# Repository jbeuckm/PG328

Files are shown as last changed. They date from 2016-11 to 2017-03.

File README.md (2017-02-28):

# PG328

Program your JX8P/JX10/MKS70 with sliders or MIDI Sysex with this Atmega328 based PG800 variation.

A .96" OLED screen shows the status and parameter values and a rotary encoder with momentary push switch provides full PG800 interface capabilities.

### MID SYSEX

#### Prefix: 

* 0x41 // manufacturer ID
* 0x36 // IPR mode
* 0x01 // device ID
* 0x24 // (from MKS70)
* 0x20 // (from MKS70)

#### Suffix:

* 0x01 // Tone

* 0x0F: Reset potentiometer assignments.

### Status:

* 2/24/17: 8-slider pcb tested. This verifies that lots of sliders can work together and will serve as ADSR for EG1 and 2.

* 12/9/16: All Parameters select and display values according to their type. Some even have lil icons...

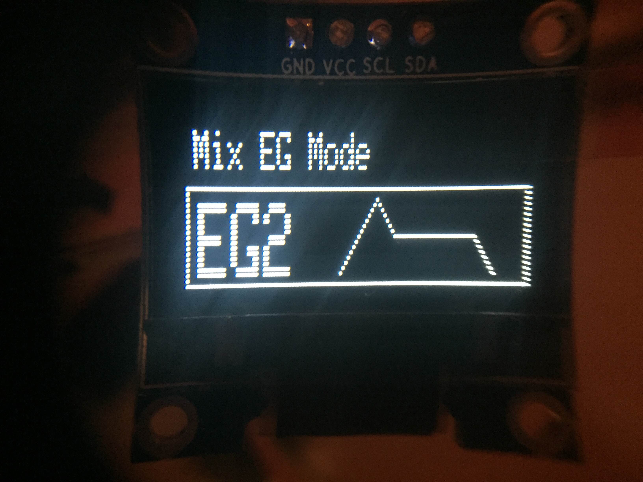
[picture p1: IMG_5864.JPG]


* 12/7/16: New Sysex message to clear all pot assignments

* 12/3/16: Stable control with encoder. Hold button to rotate parameter or just rotate to change value. Hold button down three seconds to assign slider of highest value to the current parameter.

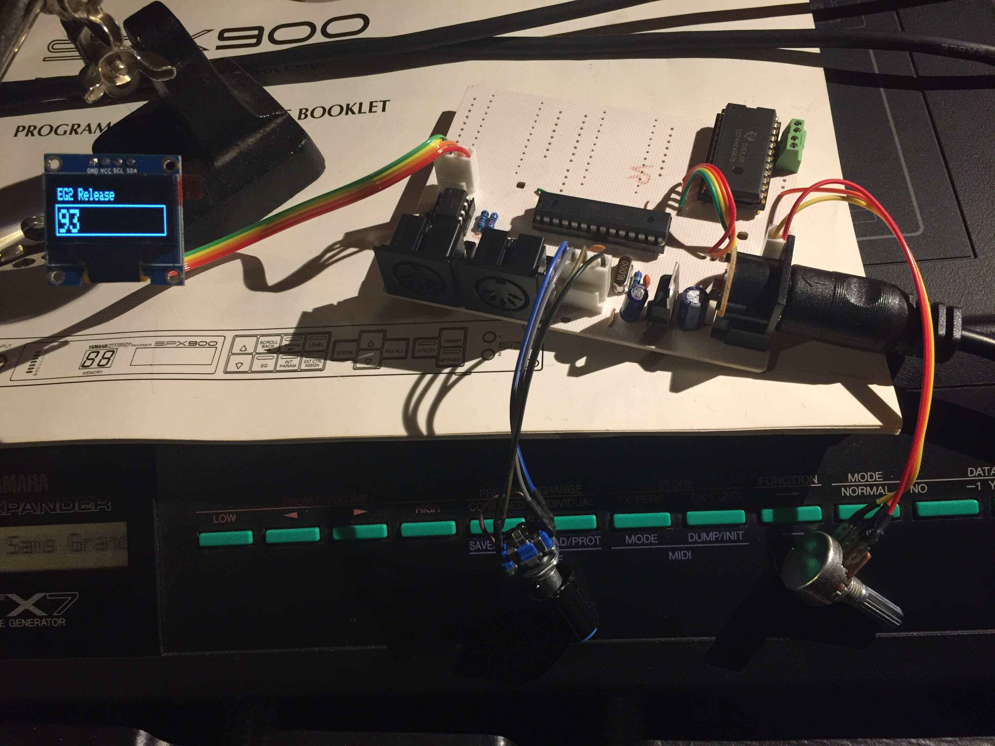
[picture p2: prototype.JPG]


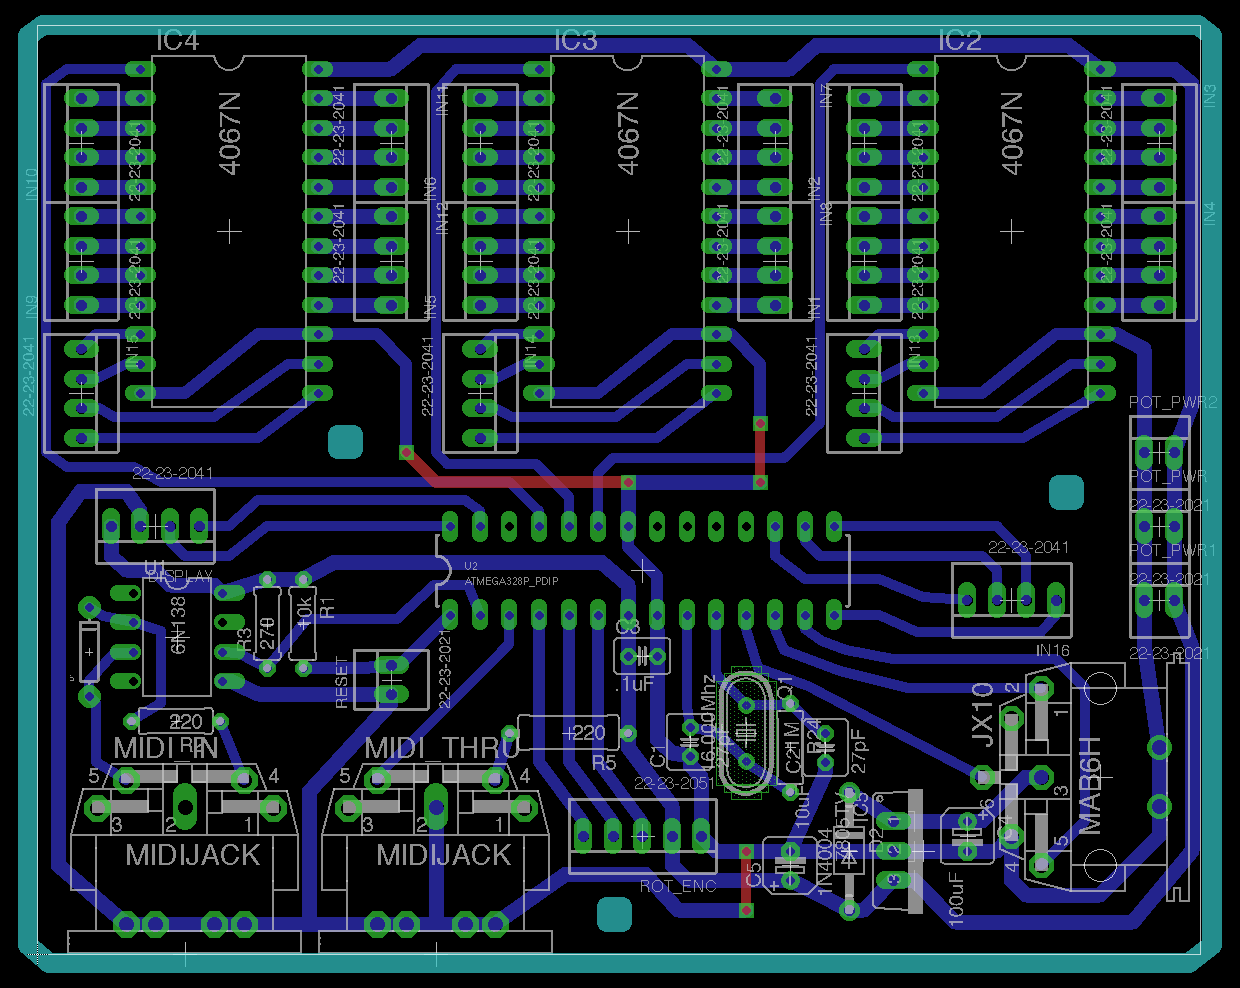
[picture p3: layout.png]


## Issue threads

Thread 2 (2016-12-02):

Set Aref a few mV below Vcc so pots always max analog in.

jbeuckm, 2016-12-02:
I am shifting the analog in value >> 3 to scale between 0 and 127. Sometimes the value will not move above 126. Setting Aref a few mV below Vcc should allow the pots to always reach max value since their max wiper voltage could exceed Aref by a tiny bit.

jbeuckm, 2016-12-06:
problem was software - no problem hitting 127 with the new rounding scheme.

Closed 2016-12-06.

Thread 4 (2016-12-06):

100nF Aref to Ground to Stabilize Analog Readings

jbeuckm, 2016-12-06:
https://forum.arduino.cc/index.php?topic=50189.msg358378#msg358378

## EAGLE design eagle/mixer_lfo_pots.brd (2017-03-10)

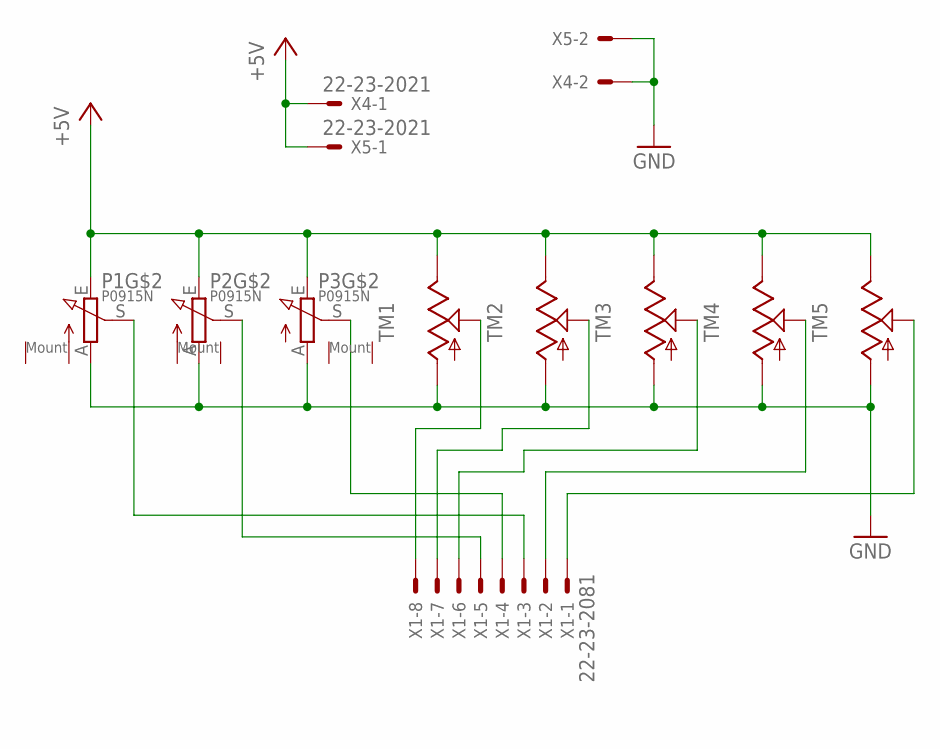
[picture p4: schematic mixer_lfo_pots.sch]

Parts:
P1, P2, P3: P0915N
TM1, TM2, TM3, TM4, TM5: TRIMSLIDE60; SLIDEPOT-60
X1: 22-23-2081
X4, X5: 22-23-2021

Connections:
+5V: P1.E, P2.E, P3.E, TM1.B, TM2.B, TM3.B, TM4.B, TM5.B, X4.1, X5.1
GND: P1.A, P2.A, P3.A, TM1.A, TM2.A, TM3.A, TM4.A, TM5.A, X4.2, X5.2
unnamed: P1.S, X1.3
unnamed: P2.S, X1.5
unnamed: P3.S, X1.4
unnamed: TM1.WIPER, X1.8
unnamed: TM2.WIPER, X1.7
unnamed: TM3.WIPER, X1.6
unnamed: TM4.WIPER, X1.2
unnamed: TM5.WIPER, X1.1

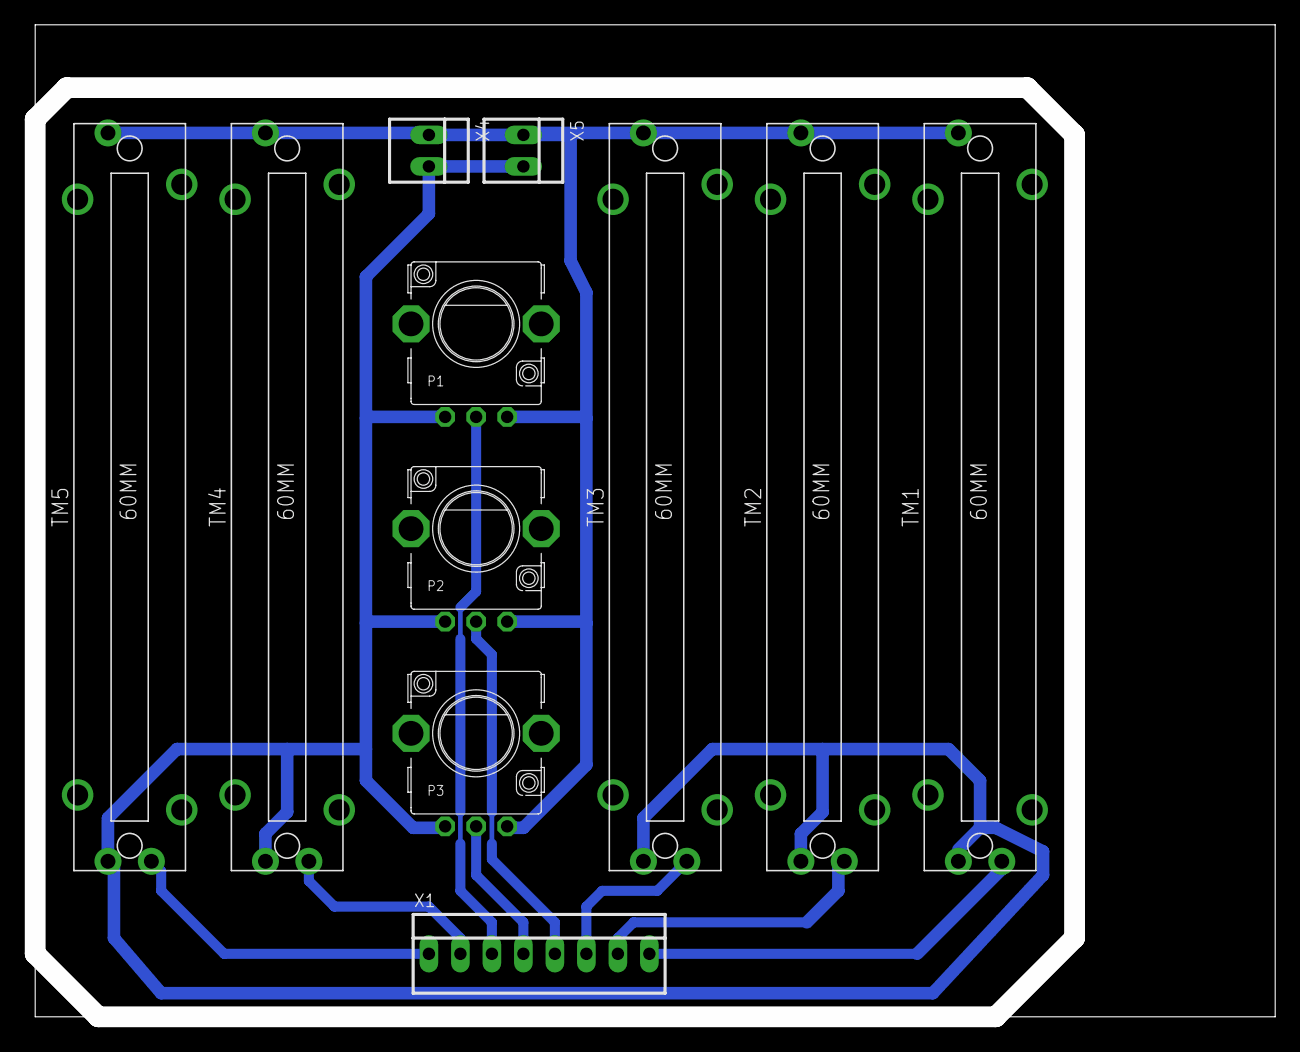
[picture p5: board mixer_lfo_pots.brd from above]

Board: 2 copper layers, 100.0 x 80.0 mm, 11 parts (0 on the bottom side), 10 nets.

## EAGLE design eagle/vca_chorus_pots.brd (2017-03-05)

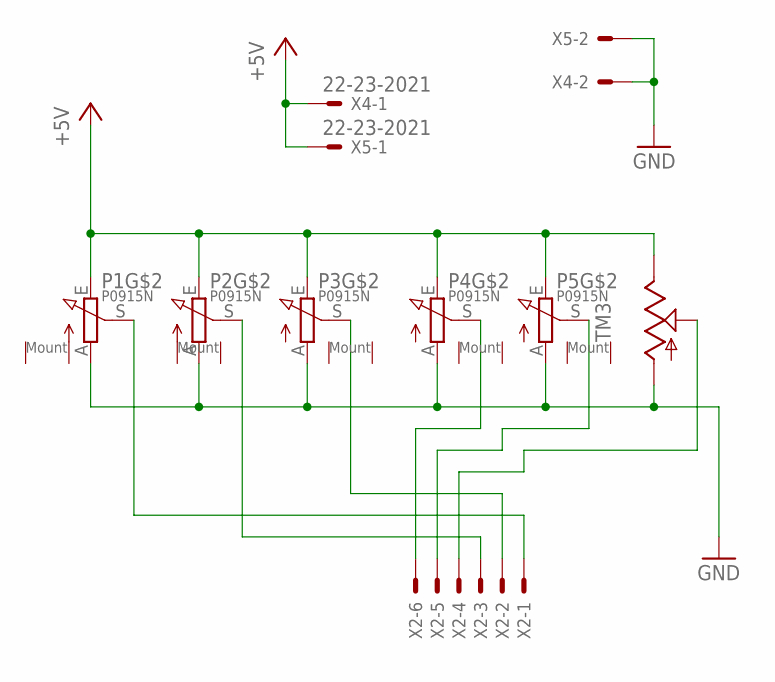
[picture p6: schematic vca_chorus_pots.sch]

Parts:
P1, P2, P3, P4, P5: P0915N
TM3: TRIMSLIDE60; SLIDEPOT-60
X2: 22-23-2061
X4, X5: 22-23-2021

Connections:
+5V: P1.E, P2.E, P3.E, P4.E, P5.E, TM3.B, X4.1, X5.1
GND: P1.A, P2.A, P3.A, P4.A, P5.A, TM3.A, X4.2, X5.2
unnamed: P1.S, X2.1
unnamed: P2.S, X2.3
unnamed: P3.S, X2.2
unnamed: P4.S, X2.6
unnamed: P5.S, X2.5
unnamed: TM3.WIPER, X2.4

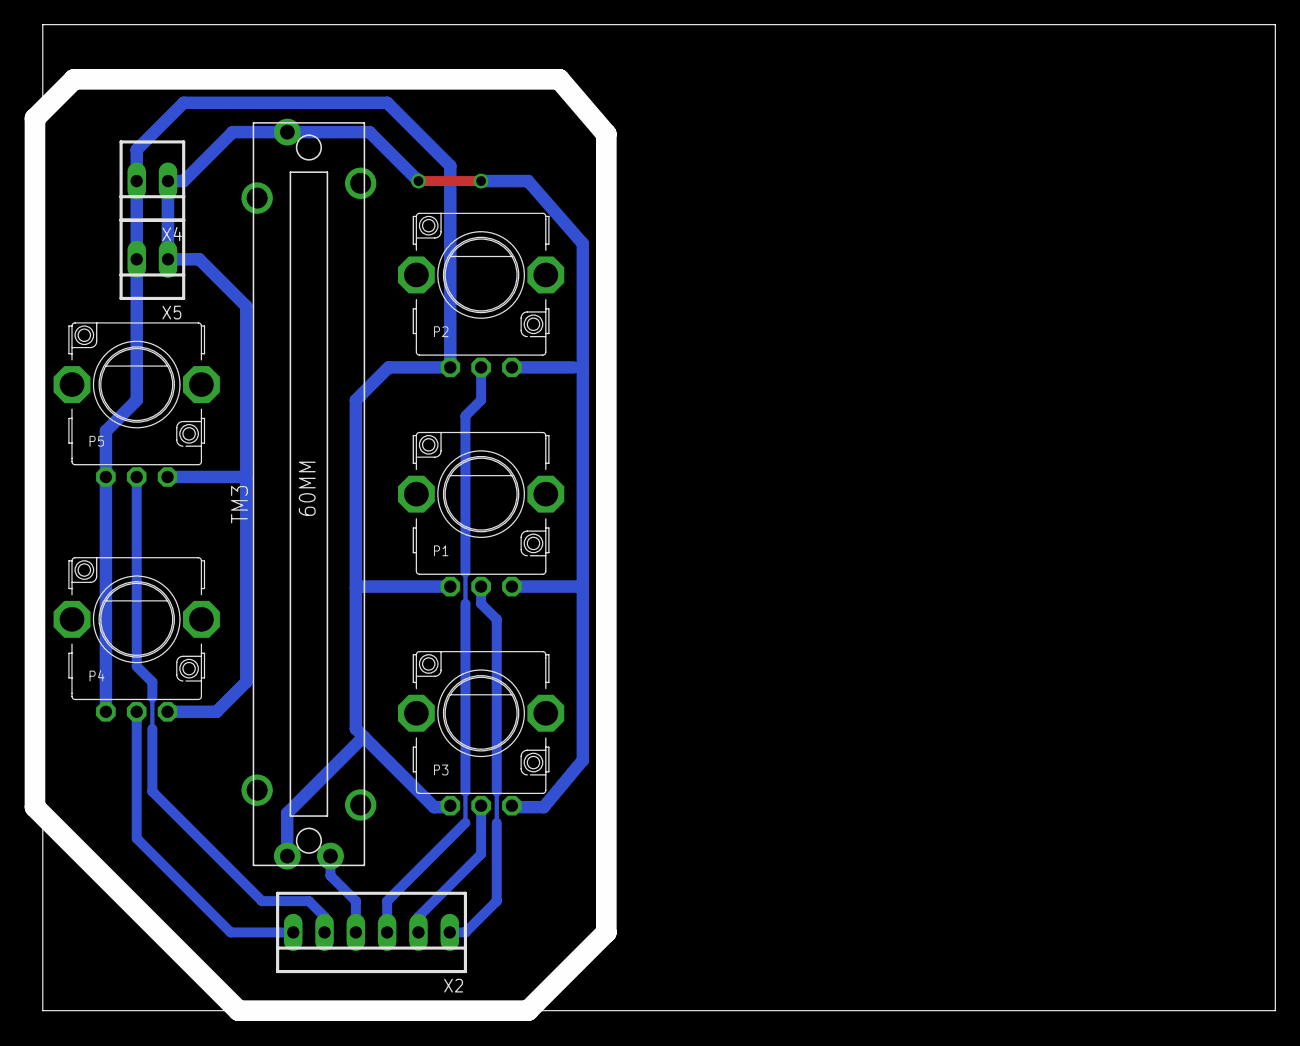
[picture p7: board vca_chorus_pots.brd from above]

Board: 2 copper layers, 100.6 x 80.0 mm, 9 parts (0 on the bottom side), 8 nets.

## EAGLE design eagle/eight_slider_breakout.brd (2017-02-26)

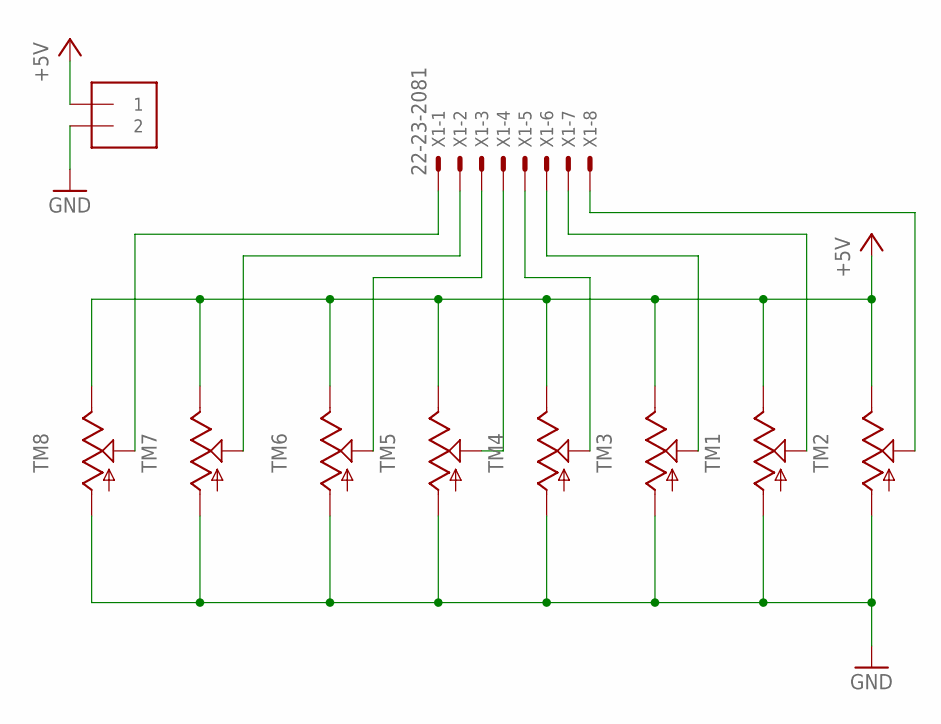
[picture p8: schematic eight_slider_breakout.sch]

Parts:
J1: 1X2-3.5MM
TM1, TM2, TM3, TM4, TM5, TM6, TM7, TM8: TRIMSLIDE60; SLIDEPOT-60
X1: 22-23-2081

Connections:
+5V: J1.1, TM1.B, TM2.B, TM3.B, TM4.B, TM5.B, TM6.B, TM7.B, TM8.B
GND: J1.2, TM1.A, TM2.A, TM3.A, TM4.A, TM5.A, TM6.A, TM7.A, TM8.A
unnamed: TM8.WIPER, X1.1
unnamed: TM7.WIPER, X1.2
unnamed: TM6.WIPER, X1.3
unnamed: TM5.WIPER, X1.4
unnamed: TM4.WIPER, X1.5
unnamed: TM3.WIPER, X1.6
unnamed: TM1.WIPER, X1.7
unnamed: TM2.WIPER, X1.8

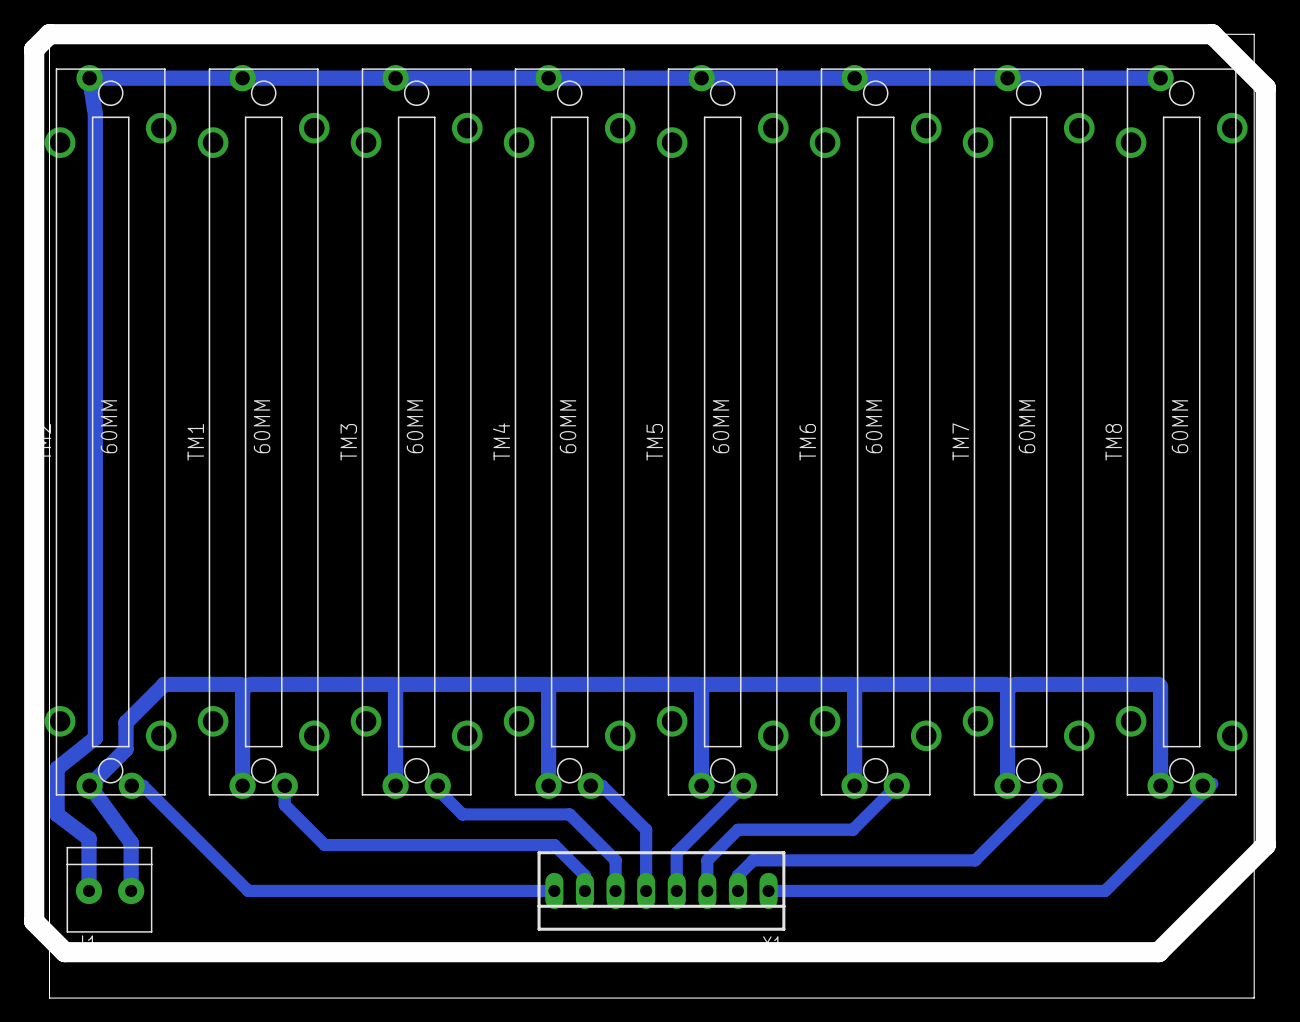
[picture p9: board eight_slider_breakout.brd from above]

Board: 2 copper layers, 102.2 x 80.0 mm, 10 parts (0 on the bottom side), 10 nets.

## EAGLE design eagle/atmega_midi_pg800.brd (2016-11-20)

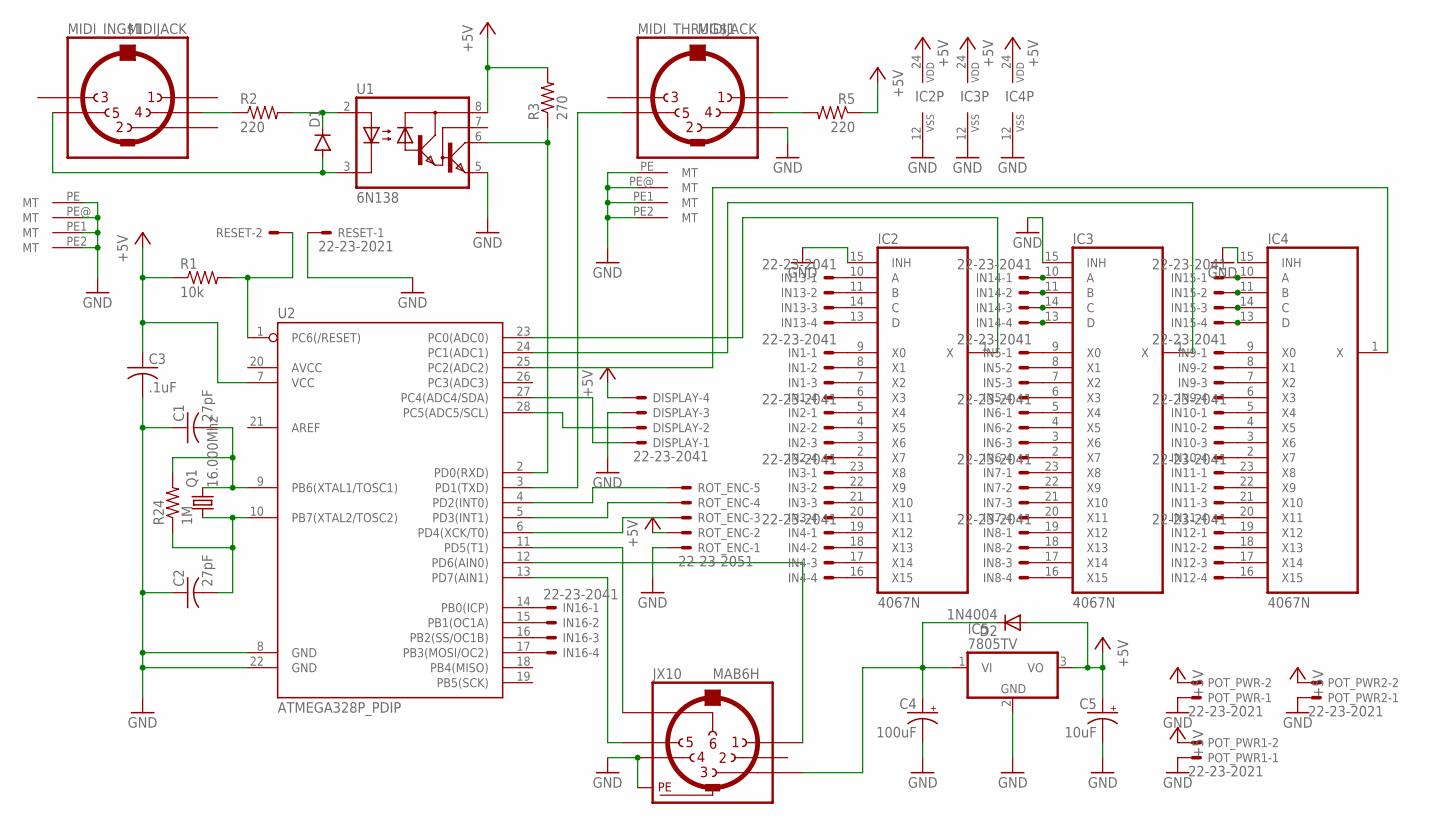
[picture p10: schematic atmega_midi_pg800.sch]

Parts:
C1, C2: 27pF; C025-040X050
C3: .1uF; C025-030X050
C4: 100uF; B45181A
C5: 10uF; B45181A
D1: DIODE1N4148; DIODE-1N4148
D2: 1N4004; DO41-10
DISPLAY: 22-23-2041
IC2, IC3, IC4: 4067N; DIL24-6
IC5: 7805TV; TO220V
IN1, IN2, IN3, IN4, IN5, IN6, IN7, IN8, IN9, IN10, IN11, IN12, IN13, IN14, IN15, IN16: 22-23-2041
JX10: MAB6H
MIDI_IN: MIDIJACK; CP-2350
MIDI_THRU: MIDIJACK; CP-2350
POT_PWR, POT_PWR1, POT_PWR2: 22-23-2021
Q1: 16.000Mhz; HC49/S
R1: 10k; 0207/7
R2: 220; 0207/7
R3: 270; 0207/7
R5: 220; 0309/10
R24: 1M; 0207/7
RESET: 22-23-2021
ROT_ENC: 22-23-2051
U1: 6N138; DIL08
U2: ATMEGA328P_PDIP; DIL28-3

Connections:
+5V: C3.1, C5.+, D2.A, DISPLAY.4, IC2.24 (VDD), IC3.24 (VDD), IC4.24 (VDD), IC5.3 (VO), POT_PWR.2, POT_PWR1.2, POT_PWR2.2, R1.1, R3.2, R5.1, ROT_ENC.2, U1.8 (VCC), U2.7 (VCC)
GND: C1.1, C2.1, C3.2, C4.-, C5.-, DISPLAY.3, IC2.12 (VSS), IC2.15 (INH), IC3.12 (VSS), IC3.15 (INH), IC4.12 (VSS), IC4.15 (INH), IC5.2 (GND), JX10.4, JX10.PE, JX10.PE@ (PE), MIDI_IN.PE (MT), MIDI_IN.PE1 (MT), MIDI_IN.PE2 (MT), MIDI_IN.PE@ (MT), MIDI_THRU.2, MIDI_THRU.PE (MT), MIDI_THRU.PE1 (MT), MIDI_THRU.PE2 (MT), MIDI_THRU.PE@ (MT), POT_PWR.1, POT_PWR1.1, POT_PWR2.1, RESET.1, ROT_ENC.1, U1.5 (GND), U2.8 (GND), U2.22 (GND)
unnamed: MIDI_THRU.4, R5.2
unnamed: IC4.1 (X), U2.25 (PC2(ADC2))
unnamed: D1.A, MIDI_IN.5, U1.3 (C)
unnamed: C1.2, Q1.2, R24.2, U2.9 (PB6(XTAL1/TOSC1))
unnamed: C2.2, Q1.1, R24.1, U2.10 (PB7(XTAL2/TOSC2))
unnamed: C4.+, D2.C, IC5.1 (VI), JX10.3
unnamed: D1.C, R2.2, U1.2 (A)
unnamed: MIDI_IN.4, R2.1
unnamed: JX10.6, U2.11 (PD5(T1))
unnamed: JX10.1, U2.12 (PD6(AIN0))
unnamed: JX10.5, U2.13 (PD7(AIN1))
unnamed: DISPLAY.2, U2.28 (PC5(ADC5/SCL))
unnamed: DISPLAY.1, U2.27 (PC4(ADC4/SDA))
unnamed: IC3.1 (X), U2.24 (PC1(ADC1))
unnamed: IC2.1 (X), U2.23 (PC0(ADC0))
unnamed: IN16.1, U2.14 (PB0(ICP))
unnamed: IN16.2, U2.15 (PB1(OC1A))
unnamed: IC3.10 (A), IN14.1
unnamed: IC3.11 (B), IN14.2
unnamed: IC2.9 (X0), IN1.1
unnamed: IC2.8 (X1), IN1.2
unnamed: IC2.7 (X2), IN1.3
unnamed: IC2.6 (X3), IN1.4
unnamed: IC2.5 (X4), IN2.1
unnamed: IC2.4 (X5), IN2.2
unnamed: IC2.3 (X6), IN2.3
unnamed: IC2.2 (X7), IN2.4
unnamed: IC2.23 (X8), IN3.1
unnamed: IC2.22 (X9), IN3.2
unnamed: R3.1, U1.6 (VO), U2.2 (PD0(RXD))
unnamed: IC2.21 (X10), IN3.3
unnamed: IC2.20 (X11), IN3.4
unnamed: IC2.19 (X12), IN4.1
unnamed: IC2.18 (X13), IN4.2
unnamed: IC2.17 (X14), IN4.3
unnamed: IC2.16 (X15), IN4.4
unnamed: IC3.9 (X0), IN5.1
unnamed: IC3.8 (X1), IN5.2
unnamed: IC3.7 (X2), IN5.3
unnamed: IC3.6 (X3), IN5.4
unnamed: IC3.5 (X4), IN6.1
unnamed: MIDI_THRU.5, U2.3 (PD1(TXD))
unnamed: R1.2, RESET.2, U2.1 (PC6(/RESET))
unnamed: IC3.4 (X5), IN6.2
unnamed: IC3.3 (X6), IN6.3
unnamed: IC3.2 (X7), IN6.4
unnamed: IC3.23 (X8), IN7.1
unnamed: IC3.22 (X9), IN7.2
unnamed: IC3.21 (X10), IN7.3
unnamed: IC3.20 (X11), IN7.4
unnamed: IC3.19 (X12), IN8.1
unnamed: IC3.18 (X13), IN8.2
unnamed: IC3.17 (X14), IN8.3
unnamed: IC3.16 (X15), IN8.4
unnamed: IC4.9 (X0), IN9.1
unnamed: IC4.8 (X1), IN9.2
unnamed: IC4.7 (X2), IN9.3
unnamed: IC4.6 (X3), IN9.4
unnamed: IC4.5 (X4), IN10.1
unnamed: IC4.4 (X5), IN10.2
unnamed: IC4.3 (X6), IN10.3
unnamed: IC4.2 (X7), IN10.4
unnamed: IC4.23 (X8), IN11.1
unnamed: IC4.22 (X9), IN11.2
unnamed: IC4.21 (X10), IN11.3
unnamed: IC4.20 (X11), IN11.4
unnamed: IC4.19 (X12), IN12.1
unnamed: IC4.18 (X13), IN12.2
unnamed: IC4.17 (X14), IN12.3
unnamed: IC4.16 (X15), IN12.4
unnamed: IC3.14 (C), IN14.3
unnamed: IC3.13 (D), IN14.4
unnamed: IC4.10 (A), IN15.1
unnamed: IC4.11 (B), IN15.2
unnamed: IC4.14 (C), IN15.3
unnamed: IC4.13 (D), IN15.4
unnamed: IN16.3, U2.16 (PB2(SS/OC1B))
unnamed: IN16.4, U2.17 (PB3(MOSI/OC2))
unnamed: IC2.13 (D), IN13.4
unnamed: IC2.14 (C), IN13.3
unnamed: IC2.11 (B), IN13.2
unnamed: IC2.10 (A), IN13.1
unnamed: ROT_ENC.5, U2.4 (PD2(INT0))
unnamed: ROT_ENC.4, U2.5 (PD3(INT1))
unnamed: ROT_ENC.3, U2.6 (PD4(XCK/T0))

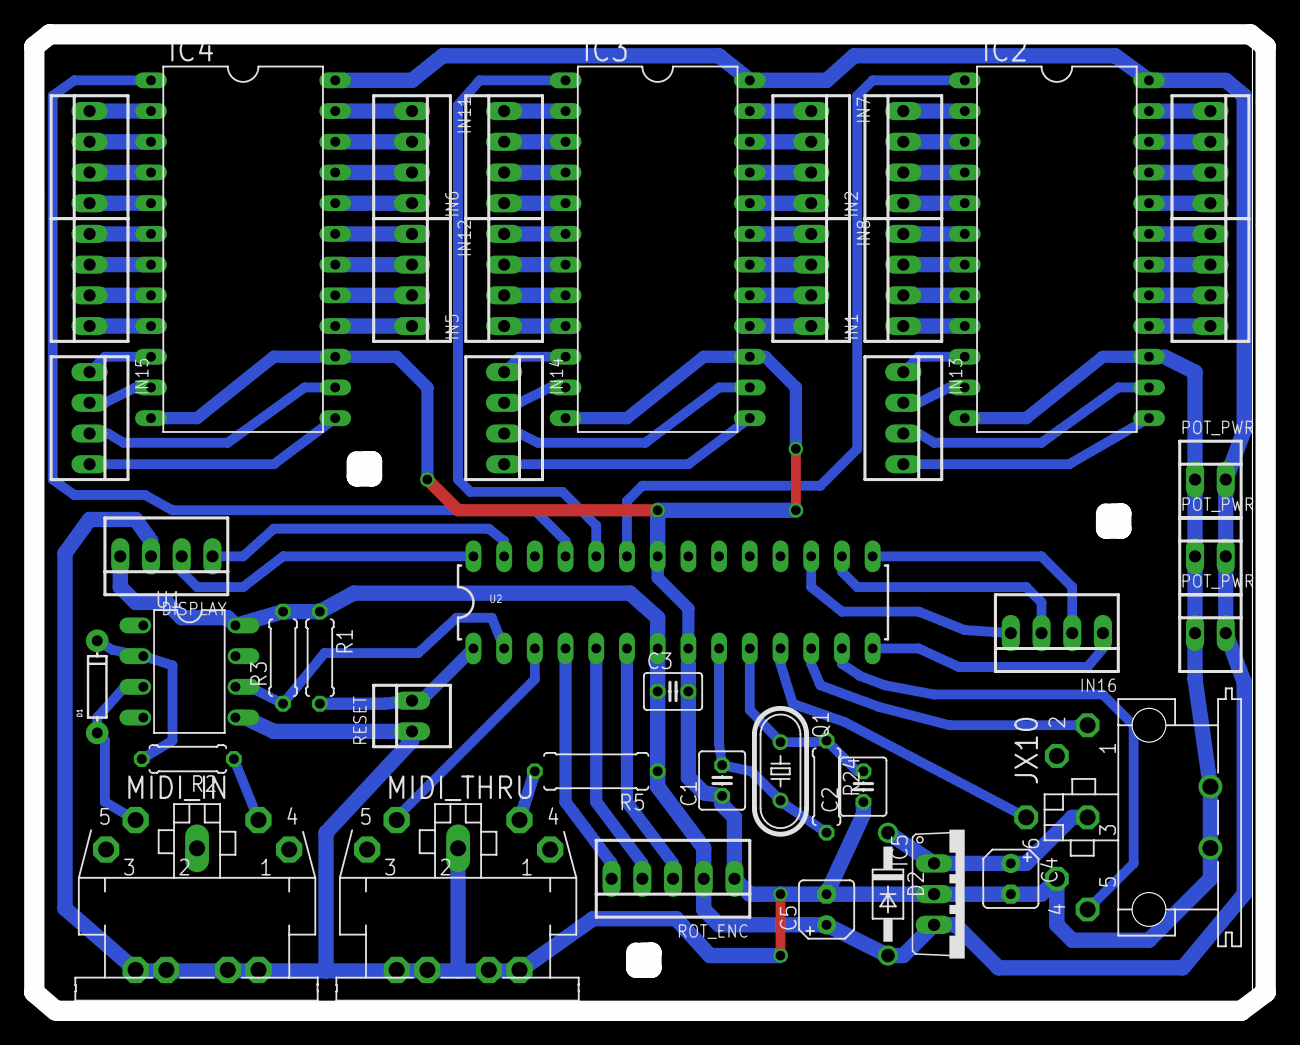
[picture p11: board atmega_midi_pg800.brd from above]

Board: 2 copper layers, 101.9 x 80.8 mm, 44 parts (0 on the bottom side), 87 nets.

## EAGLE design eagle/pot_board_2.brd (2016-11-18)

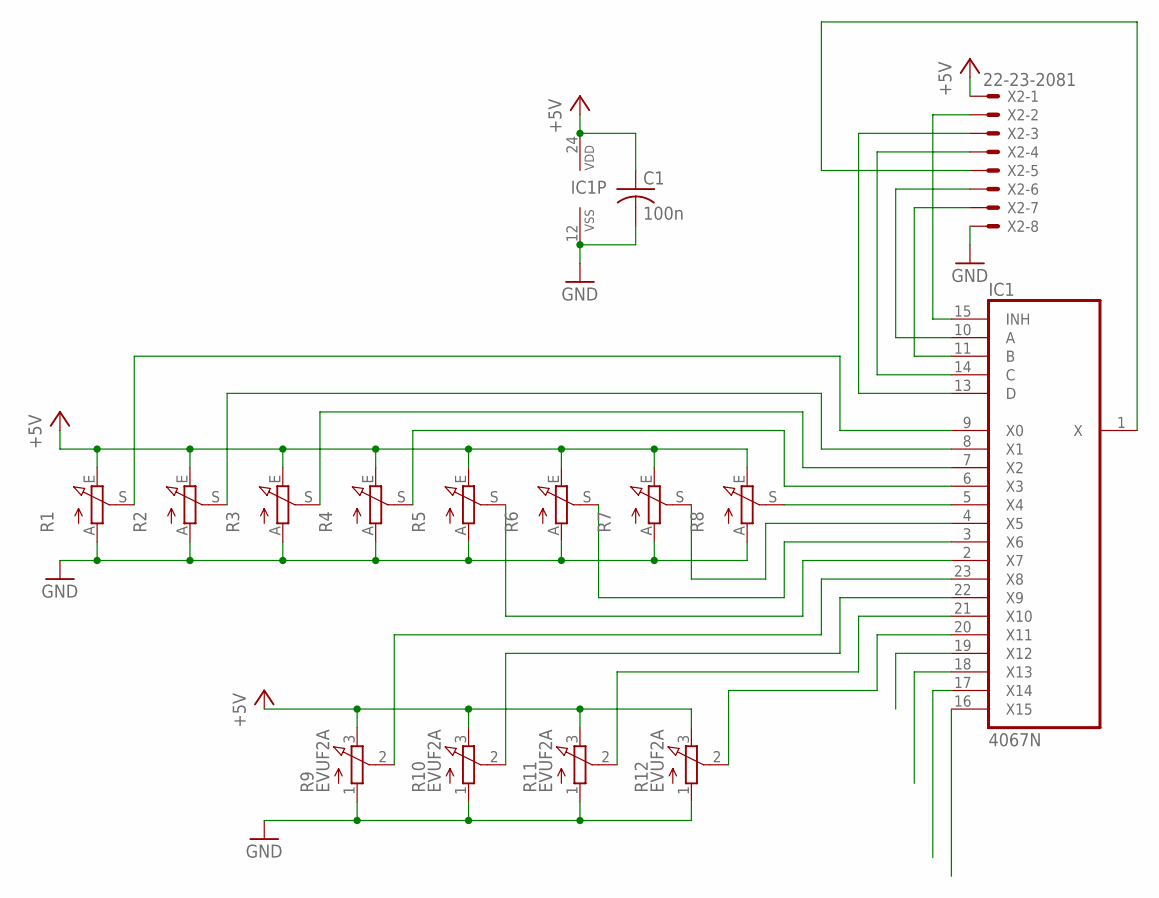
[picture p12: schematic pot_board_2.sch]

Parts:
C1: 100n; C025-024X044
IC1: 4067N; DIL24-6
R1, R2, R3, R4, R5, R6, R7, R8: 3RP/1610N45MM-SLIDE; ST15
R9, R10, R11, R12: EVUF2A; EVUF
X2: 22-23-2081

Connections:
+5V: C1.1, IC1.24 (VDD), R1.E, R2.E, R3.E, R4.E, R5.E, R6.E, R7.E, R8.E, R9.3 (E), R10.3 (E), R11.3 (E), R12.3 (E), X2.1
GND: C1.2, IC1.12 (VSS), R1.A, R2.A, R3.A, R4.A, R5.A, R6.A, R7.A, R8.A, R9.1 (A), R10.1 (A), R11.1 (A), R12.1 (A), X2.8
unnamed: IC1.9 (X0), R1.S
unnamed: IC1.8 (X1), R2.S
unnamed: IC1.7 (X2), R3.S
unnamed: IC1.6 (X3), R4.S
unnamed: IC1.5 (X4), R8.S
unnamed: IC1.4 (X5), R7.S
unnamed: IC1.3 (X6), R6.S
unnamed: IC1.2 (X7), R5.S
unnamed: IC1.15 (INH), X2.2
unnamed: IC1.23 (X8), R9.2 (S)
unnamed: IC1.11 (B), X2.7
unnamed: IC1.10 (A), X2.6
unnamed: IC1.14 (C), X2.4
unnamed: IC1.13 (D), X2.3
unnamed: IC1.1 (X), X2.5
unnamed: IC1.22 (X9), R10.2 (S)
unnamed: IC1.21 (X10), R11.2 (S)
unnamed: IC1.20 (X11), R12.2 (S)

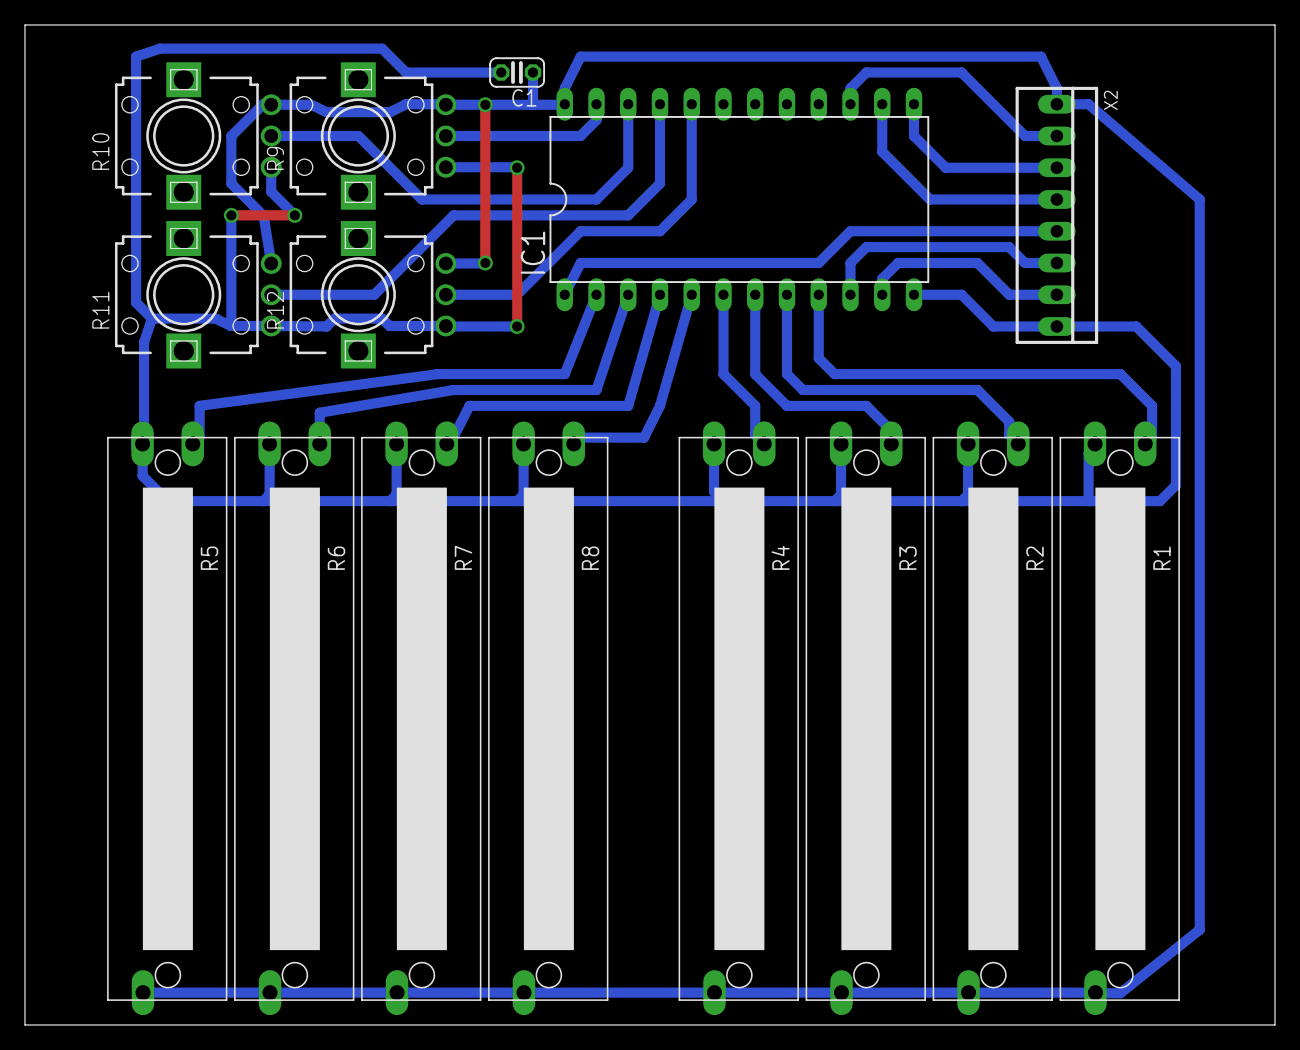
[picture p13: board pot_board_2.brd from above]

Board: 2 copper layers, 100.0 x 80.0 mm, 15 parts (0 on the bottom side), 20 nets.

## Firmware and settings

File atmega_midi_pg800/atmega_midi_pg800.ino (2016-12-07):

#include <EEPROM.h>
#include <MIDI.h>

#include <SPI.h>
#include <Wire.h>
#include <Adafruit_GFX.h>
#include <Adafruit_SSD1306.h>

#include "RotaryEncoder.h"
#include "PG800.h"

#define OLED_RESET 4
Adafruit_SSD1306 *display = new Adafruit_SSD1306(OLED_RESET);
volatile boolean displayNeedsUpdate = true;

PG800 pg800(6, 5, 7);

RotaryEncoder wheel(4);
volatile boolean changeParamMode = false;
volatile unsigned long potAssignHoldStartTime;

void buttonDown() {
  changeParamMode = true;
  displayNeedsUpdate = true;
  potAssignHoldStartTime = millis();
}
void buttonUp() {
  changeParamMode = false;
  displayNeedsUpdate = true;
}

void rotateWheel(int direction) {
  if (changeParamMode) {
    potAssignHoldStartTime = millis();
    if (direction == -1) {
      pg800.nextParam();
    } else {
      pg800.prevParam();
    }
  } else {
    if (direction == -1) {
      pg800.incValue();
    } else {
      pg800.decValue();
    }
  }
  displayNeedsUpdate = true;
}

#define NO_ASSIGNMENT 255
byte potAssigned = NO_ASSIGNMENT;

byte muxAddress;
byte potIndex;
boolean potEnabled[48];
unsigned int potReadings[48];
byte potValues[48];

// mapping pots to PG800 params
byte potAssignMap[48] = {
  0, 1, 2, 3, 4, 5, 6, 7, 8, 9,
  10, 11, 12, 13, 14, 15, 16, 17, 18, 19,
  20, 21, 22, 23, 24, 25, 26, 27, 28, 29,
  30, 31, 32, 33, 34, 35, 36, 37, 38, 39,
  40, 41, 42, 43, 44, 45, 46, 47
};


MIDI_CREATE_DEFAULT_INSTANCE();

void handleSystemExclusive(byte *message, unsigned size) {

  if (message[1] == 0x41) // manufacturer ID
  if (message[2] == 0x36) // IPR mode
//  if (message[3] == 0x01) // device ID
  if (message[4] == 0x24) // ???
  if (message[5] == 0x20) // ???
  if (message[6] == 0x01) // Tone
  {  
    pg800.setParam(message[7] - PG800_SYSEX_OFFSET);
    pg800.setValue(message[8]);
    displayNeedsUpdate = true;
  }
  else if (message[6] == 0x0f) {  // clear EEPROM
    for (int i=0; i<48; i++) {
      EEPROM.write(i, NO_ASSIGNMENT);
      potEnabled[i] = false;
    }
  }
}



void setup() {

  for (int i=0; i<48; i++) {
    byte fromROM = EEPROM.read(i);
    if (fromROM != NO_ASSIGNMENT) {
      potAssignMap[i] = fromROM;
      potEnabled[i] = true;
    }
  }
  
  DDRB = B1111; // mux address lines as outputs
  initPotValues();
  
  display->begin(SSD1306_SWITCHCAPVCC, 0x3C);  // initialize with the I2C addr 0x3C (for the 128x32)

  attachInterrupt(0, interruptA, RISING); // set an interrupt on PinA, looking for a rising edge signal and executing the "PinA" Interrupt Service Routine (below)
  attachInterrupt(1, interruptB, RISING); // set an interrupt on PinB, looking for a rising edge signal and executing the "PinB" Interrupt Service Routine (below)
  wheel.setHandleButtonDown(buttonDown);
  wheel.setHandleButtonUp(buttonUp);
  wheel.setHandleRotate(rotateWheel);

  MIDI.setHandleSystemExclusive(handleSystemExclusive);
  
  MIDI.begin();
}

void interruptA() {
  wheel.PinA();
}
void interruptB() {
  wheel.PinB();
}


void initPotValues() {

  potIndex = 0;

  for (muxAddress=0; muxAddress<16; muxAddress++) {
    PORTB = muxAddress;

    potReadings[potIndex] = analogRead(A0);
    potValues[potIndex] = analogRead(A0) >> 3;
    potIndex++;

    potReadings[potIndex] = analogRead(A1);
    potValues[potIndex] = analogRead(A1) >> 3;
    potIndex++;

    potReadings[potIndex] = analogRead(A2);
    potValues[potIndex] = analogRead(A2) >> 3;
    potIndex++;
  }
}


int findGreatestValuePot() {
  
  unsigned int greatestPotValue = 0;
  byte greatestpotIndex = 0;
  unsigned int readingValue;
  
  potIndex = 0;

  for (muxAddress=0; muxAddress<16; muxAddress++) {
    PORTB = muxAddress;

    readingValue = analogRead(A0);
    if (readingValue > greatestPotValue) {
      greatestPotValue = readingValue;
      greatestpotIndex = potIndex;
    }
    potIndex++;

    readingValue = analogRead(A1);
    if (readingValue > greatestPotValue) {
      greatestPotValue = readingValue;
      greatestpotIndex = potIndex;
    }
    potIndex++;

    readingValue = analogRead(A2);
    if (readingValue > greatestPotValue) {
      greatestPotValue = readingValue;
      greatestpotIndex = potIndex;
    }
    potIndex++;
  }

  return greatestpotIndex;
}

unsigned long syncTimeout = 0;
byte oldValue, newValue;
unsigned int analogIn;
unsigned int reading;
byte readingFraction;
byte readingWholePart;

#define UPDATE_IF_ENABLED() if (potEnabled[potIndex]) {\
  if (potValues[potIndex] != newValue) {\
    byte paramIndex = potAssignMap[potIndex];\
    pg800.setParam(paramIndex);\
    pg800.setValue(newValue);\
    potValues[potIndex] = newValue;\
    displayNeedsUpdate = true;\
  }\
}


#define PROCESS_INPUT(analogInput) {\
  analogIn = analogRead(analogInput);\
  if (analogIn < 4) {\
    potReadings[potIndex] = 0;\
    newValue = 0;\
    UPDATE_IF_ENABLED()\
  } else {\
    reading = ( (potValues[potIndex] << 4) + potReadings[potIndex] + analogIn ) >> 2;\
    potReadings[potIndex] = analogIn;\
    readingFraction = reading & B111;\
    readingWholePart = reading >> 3;\
    if (readingFraction < 3) {\
      newValue = readingWholePart;\
      UPDATE_IF_ENABLED()\
    }\
    else if (readingFraction < 6) {\
      if (potValues[potIndex] != readingWholePart) {\
        if (potValues[potIndex] != (readingWholePart + 1)) {\
          newValue = readingWholePart;\
          UPDATE_IF_ENABLED()\
        }\
      }\
    }\
    else {\
      newValue = readingWholePart + 1;\
      UPDATE_IF_ENABLED()\
    }\
  }\
}



void loop() {

  potIndex = 0;

  for (muxAddress=0; muxAddress<16; muxAddress++) {
    PORTB = muxAddress;

    PROCESS_INPUT(A0)
    potIndex++;
    
    PROCESS_INPUT(A1)
    potIndex++;
    
    PROCESS_INPUT(A2)
    potIndex++;
  }
  
  MIDI.read();
  
  wheel.checkButton();

  if (changeParamMode && ((millis() - potAssignHoldStartTime) > 3000)) {
    int greatestpotIndex = findGreatestValuePot();
    potAssignMap[greatestpotIndex] = pg800.getParamIndex();
    EEPROM.write(greatestpotIndex, pg800.getParamIndex());
    potAssigned = greatestpotIndex;
    potEnabled[greatestpotIndex] = true;
    displayNeedsUpdate = true;
    potAssignHoldStartTime = millis();
  }

  if (displayNeedsUpdate) {

    detachInterrupt(0);
    detachInterrupt(1);
    updateDisplay();
    attachInterrupt(0, interruptA, RISING);
    attachInterrupt(1, interruptB, RISING);
    
    displayNeedsUpdate = false;
  }

  if ((millis() - syncTimeout) > 5) {
    cli();
    pg800.sync();
    sei();
    syncTimeout = millis();
  }
}


void updateDisplay() {
  
  display->clearDisplay();
  display->setTextColor(WHITE);

  if (potAssigned != NO_ASSIGNMENT) {
    display->setCursor(3,3);
    display->setTextSize(1);
    display->print(potAssigned);
    display->print(" --> ");
    display->print(pg800.paramName());
    display->display();
    potAssigned = NO_ASSIGNMENT;
    delay(2000);
    return;
  }

  display->setCursor(3,3);
  display->setTextSize(1);
  display->print(pg800.paramName());

  if (changeParamMode) {
    display->drawRect(0,0,128,13,WHITE);
  } else {
    display->drawRect(0,13,128,19,WHITE);
  }

  pg800.drawParamValue(display);

  display->display();
}

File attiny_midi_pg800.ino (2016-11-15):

#include <EEPROM.h>
#include <SoftwareSerialIn.h>
#include <MIDI.h>

#define CTRL_RESET 121

#define READY 0
#define CLOCK_IN 1
#define DATA_OUT 2

#define MIDI_CHANNEL_ADDRESS 0

SoftwareSerialIn mSerial(5);
MIDI_CREATE_INSTANCE(SoftwareSerialIn, mSerial, midiIn);

byte selectedChannel = 3;


void sendByte(byte data) {
  
  digitalWrite(READY, HIGH);
  
  byte mask = B1000000;
  
  for (int i=0; i<8; i++) {
    while (digitalRead(CLOCK_IN) == LOW) {
      delayMicroseconds(1);
    }
    if (data & mask) {
      digitalWrite(DATA_OUT, HIGH);
    } else {
      digitalWrite(DATA_OUT, LOW);
    }
    while (digitalRead(CLOCK_IN) == HIGH) {
      delayMicroseconds(1);
    }
    mask >>= 1;
  }
  
  digitalWrite(READY, LOW);
  
}

void handleSystemExclusive(byte *message, unsigned size) {

  if (message[1] == 0x77) // manufacturer ID
  if (message[2] == 0x10)    // model ID
  if (message[3] == 0) {  // device ID
    selectedChannel = message[4] % 17;
    EEPROM.write(MIDI_CHANNEL_ADDRESS, selectedChannel);
    midiIn.begin(selectedChannel);
    
  }
}


void handleControlChange(byte channel, byte number, byte value)
{
  switch (number) {

    case CTRL_RESET:
      break;
      
  }   
}

void setup() {

  pinMode(READY, OUTPUT);
  digitalWrite(READY, LOW);

  pinMode(DATA_OUT, OUTPUT);
  digitalWrite(DATA_OUT, LOW);

  pinMode(CLOCK_IN, INPUT);

  selectedChannel = EEPROM.read(MIDI_CHANNEL_ADDRESS);
  if (selectedChannel > 16) {
    selectedChannel = 0;
    EEPROM.write(MIDI_CHANNEL_ADDRESS, selectedChannel);
  }

  midiIn.setHandleSystemExclusive(handleSystemExclusive);
  midiIn.setHandleControlChange(handleControlChange);
  
  midiIn.begin(selectedChannel);
}

void loop() {
  midiIn.read();  
}

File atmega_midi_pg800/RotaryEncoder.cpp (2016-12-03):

#include "RotaryEncoder.h"


void RotaryEncoder::PinA(){
  cli(); //stop interrupts happening before we read pin values
  reading = PIND & 0xC; // read all eight pin values then strip away all but pinA and pinB's values
  if(reading == B00001100 && aFlag) { //check that we have both pins at detent (HIGH) and that we are expecting detent on this pin's rising edge
    
    if (mRotateCallback != 0) mRotateCallback(-1);
    
    bFlag = 0; //reset flags for the next turn
    aFlag = 0; //reset flags for the next turn
  }
  else if (reading == B00000100) bFlag = 1; //signal that we're expecting pinB to signal the transition to detent from free rotation
  sei(); //restart interrupts
}

void RotaryEncoder::PinB(){
  cli(); //stop interrupts happening before we read pin values
  reading = PIND & 0xC; //read all eight pin values then strip away all but pinA and pinB's values
  if (reading == B00001100 && bFlag) { //check that we have both pins at detent (HIGH) and that we are expecting detent on this pin's rising edge
    
    if (mRotateCallback != 0) mRotateCallback(1);
    
    bFlag = 0; //reset flags for the next turn
    aFlag = 0; //reset flags for the next turn
  }
  else if (reading == B00001000) aFlag = 1; //signal that we're expecting pinA to signal the transition to detent from free rotation
  sei(); //restart interrupts
}

RotaryEncoder::RotaryEncoder(int buttonPin) {

  buttonState = false;
  BUTTON_PIN = buttonPin;

  mRotateCallback = 0;
  mButtonDownCallback = 0;
  mButtonUpCallback = 0;

  aFlag = 0; // let's us know when we're expecting a rising edge on pinA to signal that the encoder has arrived at a detent
  bFlag = 0; // let's us know when we're expecting a rising edge on pinB to signal that the encoder has arrived at a detent (opposite direction to when aFlag is set)
  reading = 0; //somewhere to store the direct values we read from our interrupt pins before checking to see if we have moved a whole detent

  pinMode(BUTTON_PIN, INPUT_PULLUP);
  pinMode(pinA, INPUT_PULLUP); // set pinA as an input, pulled HIGH to the logic voltage (5V or 3.3V for most cases)
  pinMode(pinB, INPUT_PULLUP); // set pinB as an input, pulled HIGH to the logic voltage (5V or 3.3V for most cases)
}


boolean RotaryEncoder::checkButton() {
  boolean newState = digitalRead(BUTTON_PIN);

  if (!newState && buttonState) {
    if (mButtonDownCallback != 0) mButtonDownCallback();
    buttonState = newState;
  }
  else if (newState && !buttonState) {
    if (mButtonUpCallback != 0) mButtonUpCallback();
    buttonState = newState;
  }

  return newState;
}


void RotaryEncoder::setHandleRotate(void (*fptr)(int direction)) { mRotateCallback = fptr; }
void RotaryEncoder::setHandleButtonDown(void (*fptr)(void)) { mButtonDownCallback = fptr; }
void RotaryEncoder::setHandleButtonUp(void (*fptr)(void)) { mButtonUpCallback = fptr; }

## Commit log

2016-11-15 porting up to atmega328 for arduino compat etc
2016-11-16 starting eagle schemo
    [atmega_midi_pg800.brd, atmega_midi_pg800.sch]
2016-11-17 16 sliders
    [pot_board.brd, pot_board.sch, pot_board_2.brd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]
2016-11-17 added oled disply connection
    [atmega_midi_pg800.brd, atmega_midi_pg800.sch]
2016-11-17 mux coming in
    [atmega_midi_pg800.brd, atmega_midi_pg800.sch]
2016-11-17 muxes with input holes
    [atmega_midi_pg800.brd, atmega_midi_pg800.sch]
2016-11-17 input terminals wired
    [atmega_midi_pg800.brd, atmega_midi_pg800.sch]
2016-11-17 placement improved
    [atmega_midi_pg800.brd, atmega_midi_pg800.sch]
2016-11-17 placed again
    [atmega_midi_pg800.brd]
2016-11-18 standard connector for display
    [atmega_midi_pg800.brd, atmega_midi_pg800.sch, pot_board_2.brd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]
2016-11-18 rotary encoder connection
    [atmega_midi_pg800.brd, atmega_midi_pg800.sch]
2016-11-18 big boy version of 7805 to power those 4067 and the display
    [atmega_midi_pg800.brd, atmega_midi_pg800.sch]
2016-11-18 protectoin diode and pot power hookups
    [atmega_midi_pg800.brd, atmega_midi_pg800.sch]
2016-11-19 tried gcode
    [atmega_midi_pg800.sch]
2016-11-20 moved a resistor away from midi in jack
    [atmega_midi_pg800.brd]
2016-11-25 running rotary encoder and oled screen
2016-11-25 initializing encoder with a switch pin
2016-11-26 button callbacks
2016-11-26 change param while button down
2016-11-28 corrected mask to start on bit 7
    [PG800.cpp]
2016-11-29 fixed pg800 interface pins
    [atmega_midi_pg800.ino]
2016-12-03 direction reversed and pot not ignored
    [atmega_midi_pg800.ino]
2016-12-03 detaching encoder interrupt during display update and no lockups
2016-12-03 move encoder interrupt toggling into main loop and faster averaging
2016-12-03 pcb layout
2016-12-03 ignore sysex device id for now
2016-12-05 potAssigned is byte, new rounding loop for pots, ignore sysex device id
2016-12-06 sysex command to reset pot assignments
    [atmega_midi_pg800.ino]
2017-02-19 testing library for the sliders i bought
    [pta_series_pot_test.brd]
2017-02-25 slider board
    [eight_slider_breakout.brd, eight_slider_breakout.sch, pta_series_pot_test.sch]
2017-02-26 working up 14 pots for vco controls
    [vco_pots.brd, vco_pots.sch]
2017-02-26 schemo wired
    [vco_pots.brd, vco_pots.sch]
2017-02-26 cutout for vco controls
    [vco_pots.brd]
2017-02-26 corrected jumper between sliders
    [vco_pots.brd]
2017-02-26 moved pcb to zero corner
    [vco_pots.brd]
2017-02-28 vcf pot board
    [vcf_pots.brd, vcf_pots.sch, vco_pots.brd]
2017-03-05 routed vca pot brd
    [mixer_lfo_pots.brd, mixer_lfo_pots.sch, vca_chorus_pots.brd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]
2017-03-06 the last pcb
2017-03-10 panel shape
    [mixer_lfo_pots.brd]
2017-03-15 filter labels
2017-03-16 mounting holes

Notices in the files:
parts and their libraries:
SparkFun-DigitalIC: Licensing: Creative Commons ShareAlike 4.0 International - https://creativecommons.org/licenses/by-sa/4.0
